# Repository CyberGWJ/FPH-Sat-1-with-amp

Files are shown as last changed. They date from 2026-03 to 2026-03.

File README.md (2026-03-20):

Designed a case for a Future Proof Homes Satillite 1 with an amplifier.  There are two version, one for a 30w amp and a large one for a 220w amp.

The design uses a slide in amp PCB base so a different amp PCB could be used without modifying the rest of the case.  

All STL and STEP files are posted.  

There is an Assembly Guide in the Docs folder.

Notes: 
Currently there are slicer files (Bambu Slicer and Orca Slicer) for multi-filament printers.  A version has been added for single filament printers (Orca Slicer only).

The LED ring has special print settings to improve the LED display.  If copying the files be sure to review the settings.

There are mounts for the LD2450 and Wi-Fi antenna.  This for the new hat version with ports on the bottom of the board.

UPDATE 3/20/2026
Added TPA3116D2 PCB, 3.5mm shielded audio cable, updated slicer files and Assembly Guide, and reorganized files.

Recommend using PCBs with an audio jack and shielded cable.

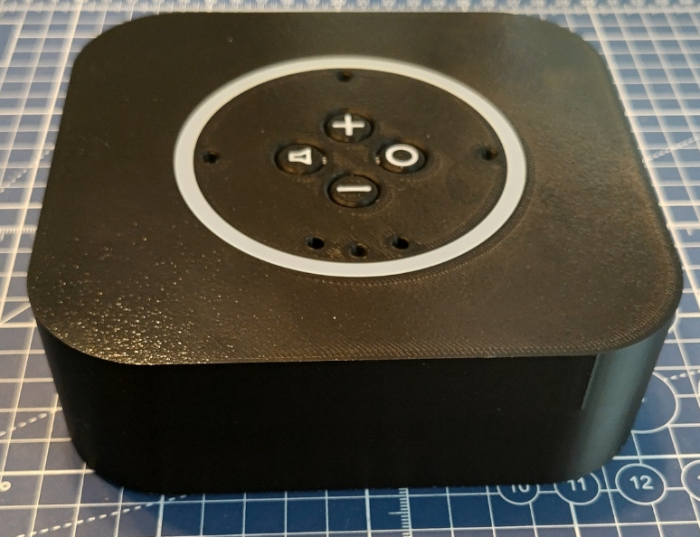
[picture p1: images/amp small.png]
Amp Case


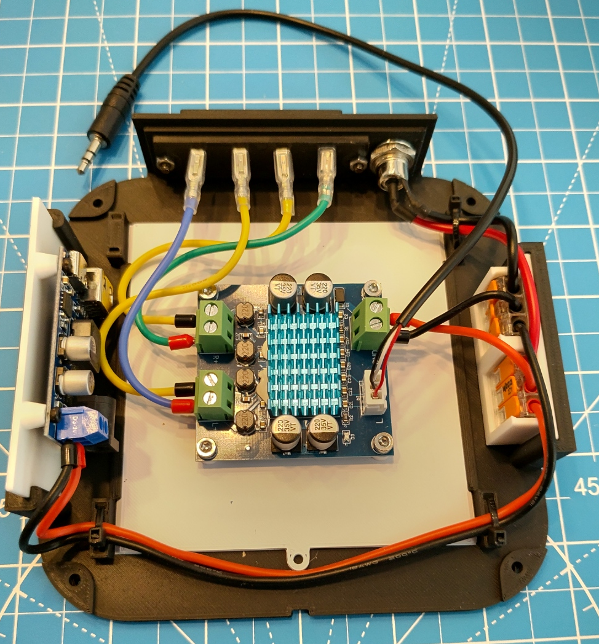
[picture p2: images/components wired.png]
Wired


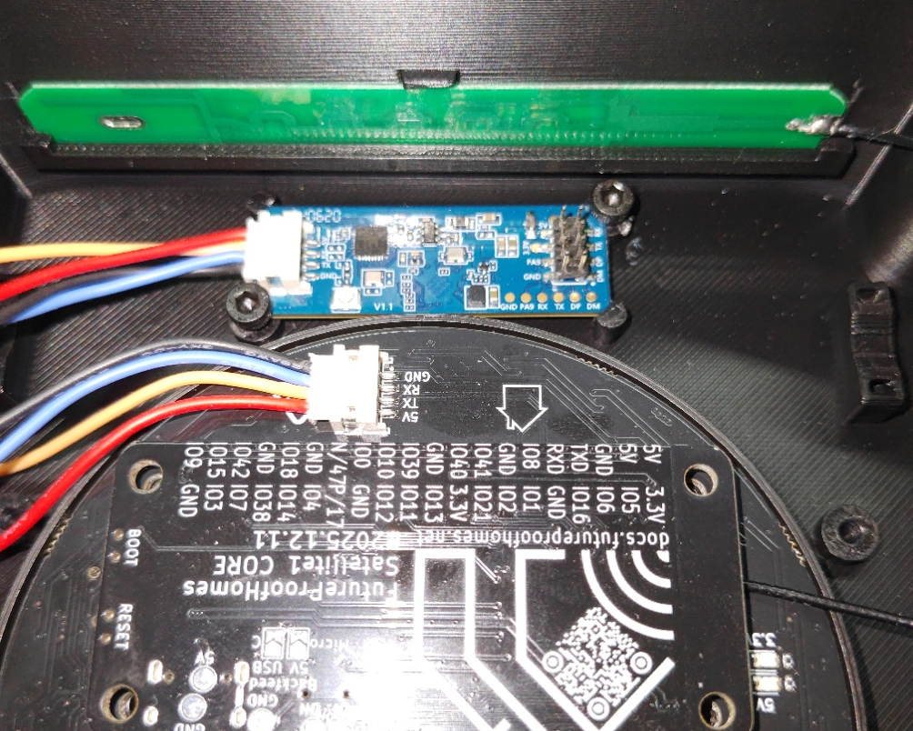
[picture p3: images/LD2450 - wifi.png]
LD2450 & Wi-Fi


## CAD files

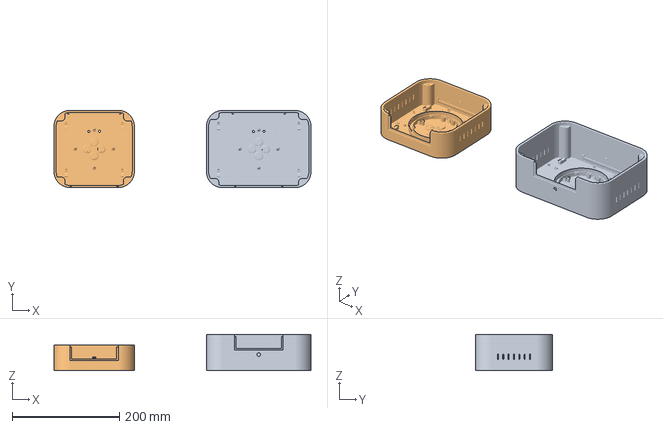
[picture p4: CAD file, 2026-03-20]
Amp Case Top - Orca Slicer MFP.3mf
479.5 x 144.2 x 67.8 mm
case top - large.step
case top.step

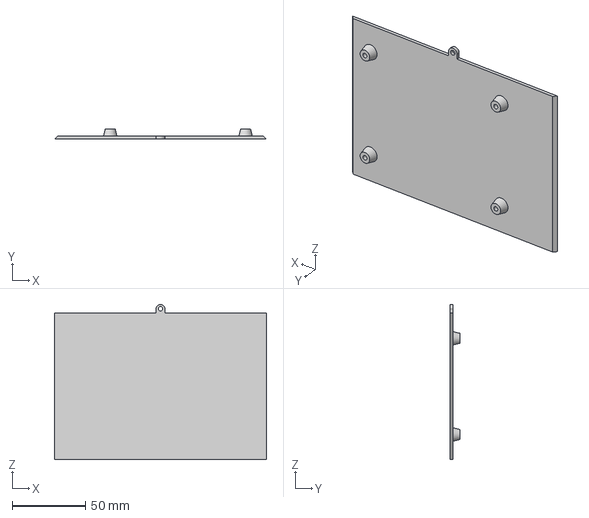
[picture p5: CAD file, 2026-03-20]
Geometry/STEP/amp pcb mount - TPA3251.step
144.8 x 7.00 x 106.0 mm

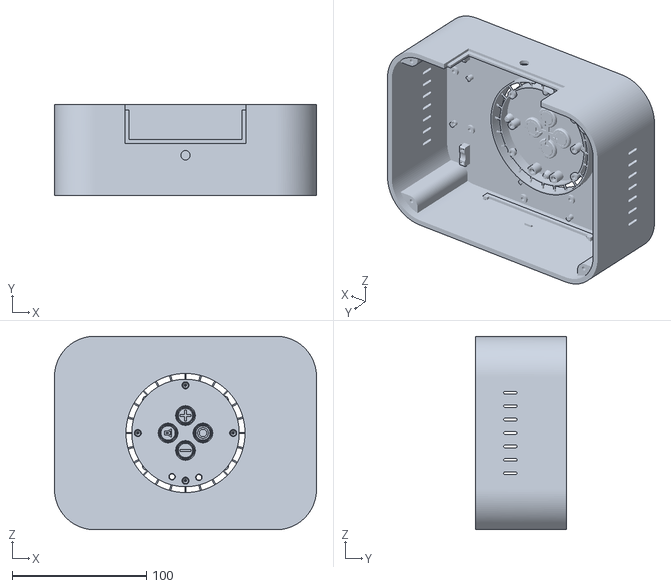
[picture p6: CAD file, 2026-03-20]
Geometry/STL/case top - large - led cutout.stl
195.0 x 67.8 x 144.0

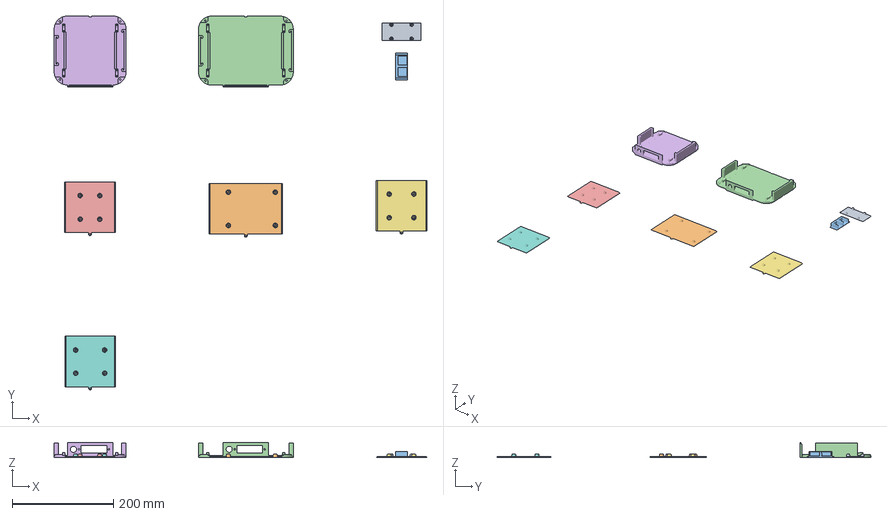
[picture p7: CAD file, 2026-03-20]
Amp Base - Orca Slicer.3mf
734.7 x 737.2 x 29.0 mm
Buck Mount.stl
amp pcb mount - TPA3251.stl
221-413.stl
amp base - large.stl
amp pcb mount - TPA3110.stl
amp base.stl
amp pcb mount - TPA3110 with mounts.stl
amp pcb mount - TPA3116D2.stl

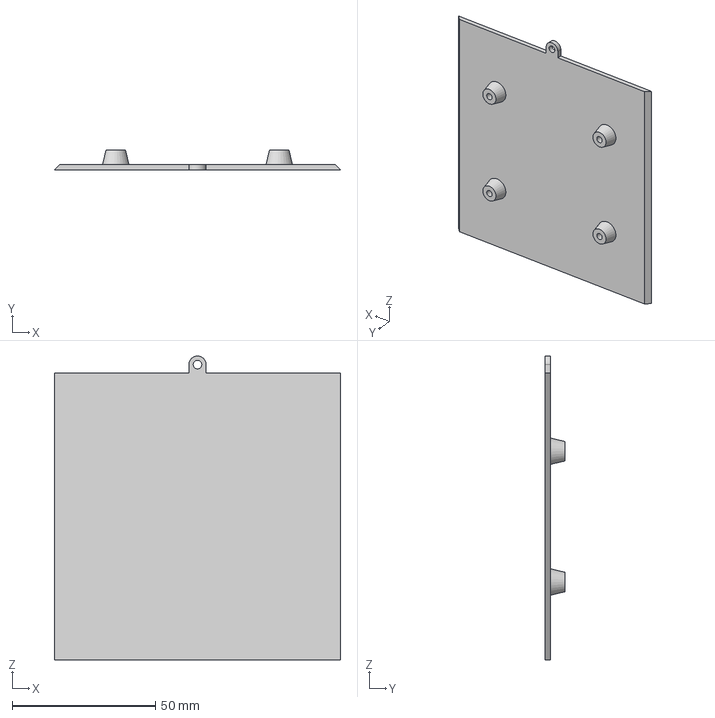
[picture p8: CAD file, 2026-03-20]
Geometry/STEP/amp pcb mount - TPA3116D2.step
99.8 x 7.00 x 106.0 mm

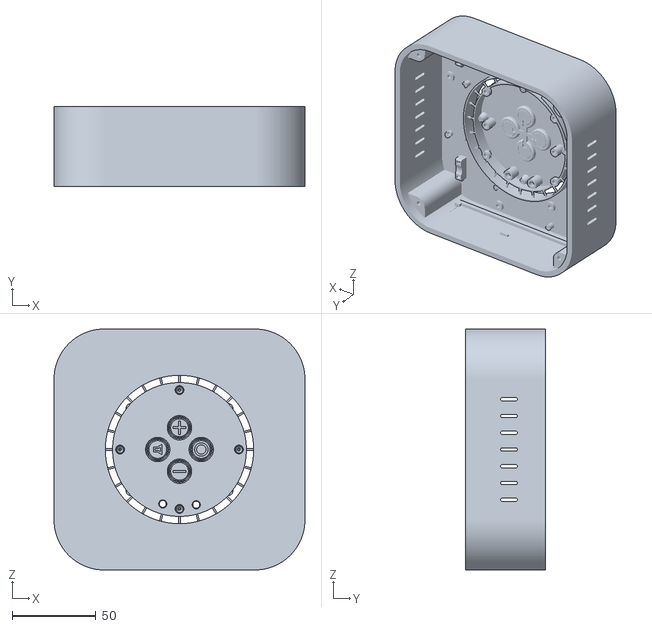
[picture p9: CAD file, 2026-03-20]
Geometry/STL/case top - led cutout.stl
150.0 x 47.8 x 144.0

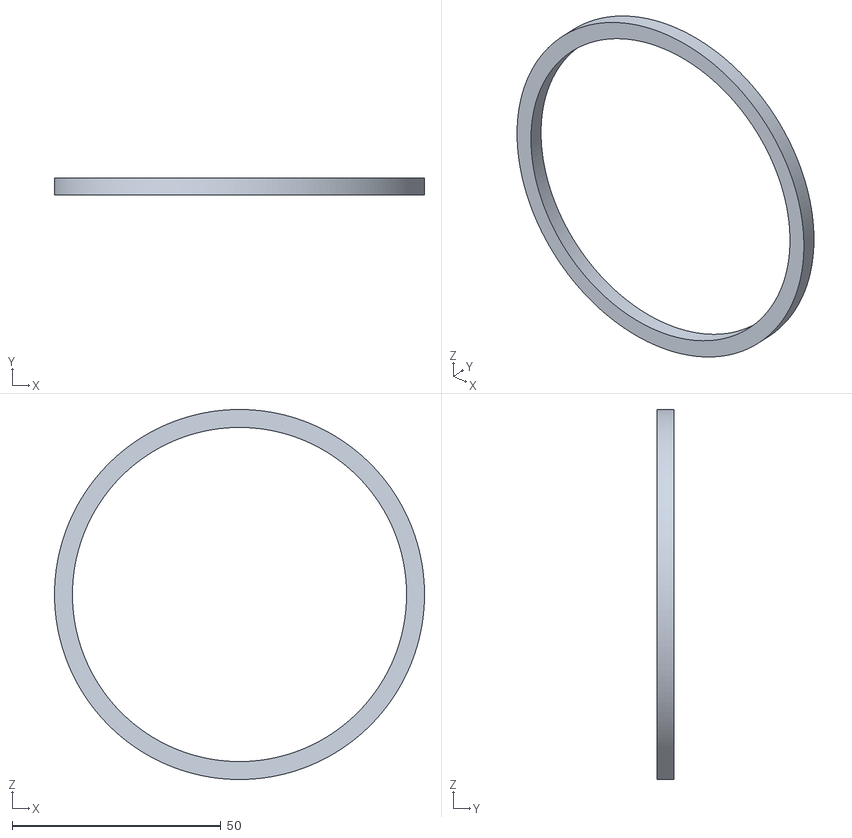
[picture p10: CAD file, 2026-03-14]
Geometry/STL/LED ring.stl
88.6 x 4.00 x 88.6

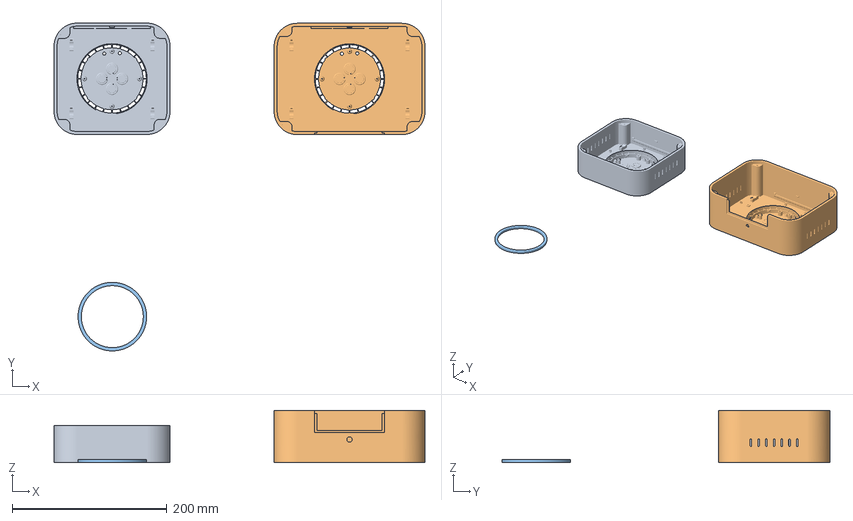
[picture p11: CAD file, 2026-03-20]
Amp Case Top - Orca Slicer SFP.3mf
479.5 x 423.7 x 67.8 mm
case top - led cutout.stl
case top - large - led cutout.stl
LED ring.stl

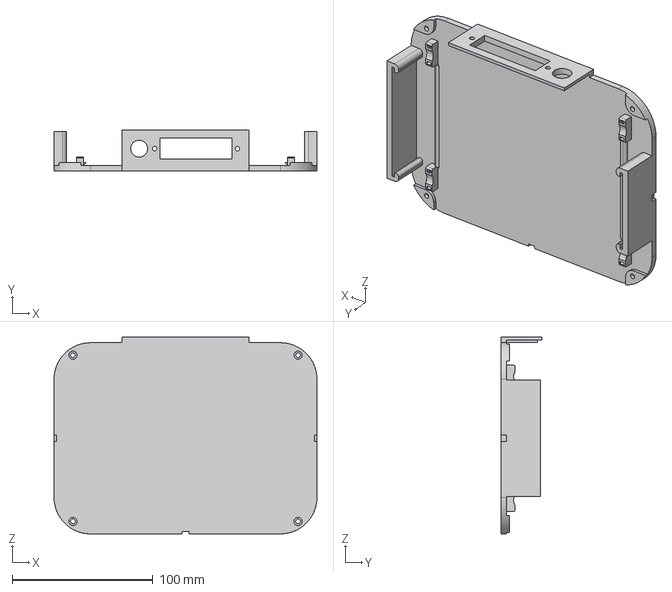
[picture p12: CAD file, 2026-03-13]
Geometry/STEP/amp base - large.step
187.0 x 29.0 x 140.0 mm

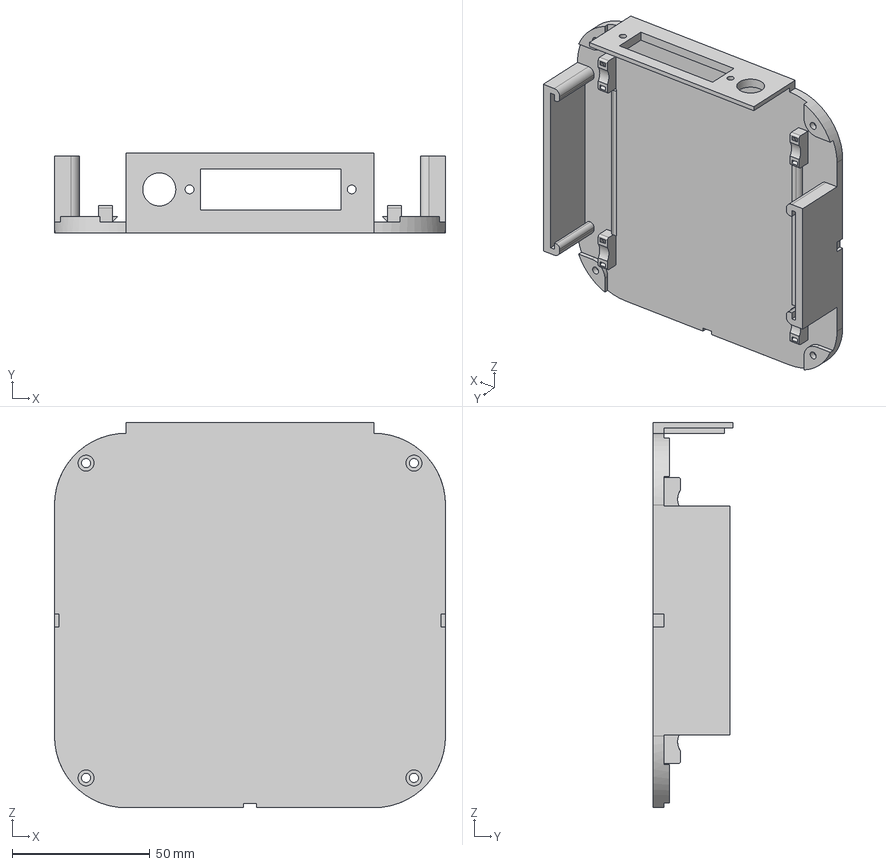
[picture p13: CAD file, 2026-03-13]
Geometry/STEP/amp base.step
142.0 x 29.0 x 140.0 mm

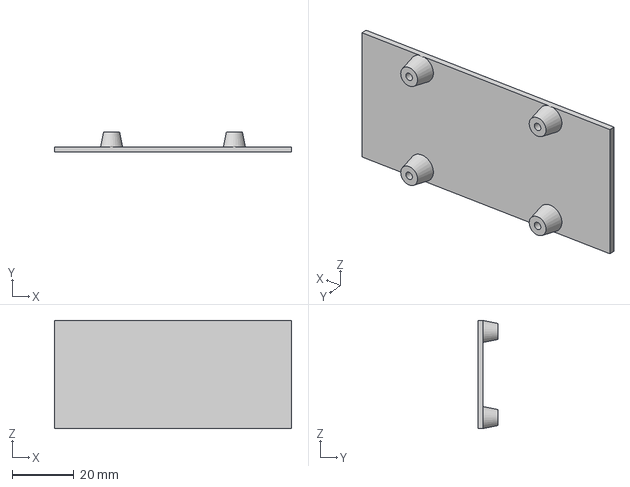
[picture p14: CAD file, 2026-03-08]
Geometry/STEP/buck mount.step
76.8 x 6.60 x 35.0 mm

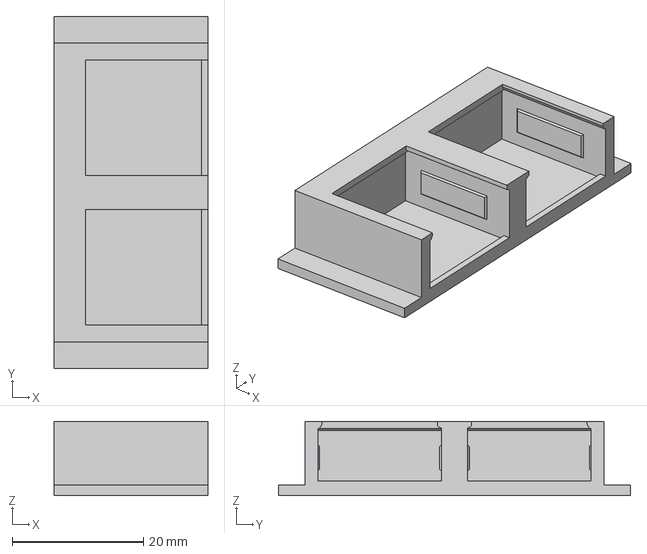
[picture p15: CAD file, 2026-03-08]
Geometry/STEP/wago 221-413.step
23.4 x 53.6 x 11.3 mm

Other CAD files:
Amp Base - Bambu Studio.3mf
Geometry/STEP/case top - large.step
Amp Case Top - Bambu Studio MFP.3mf
Geometry/STEP/amp pcb mount - TPA3110 with mounts.step
Geometry/STEP/amp pcb mount - TPA3110.step
Geometry/STEP/case top.step
Geometry/STEP/amp pcb mount - large.step
Geometry/STL/Buck Mount.stl
Geometry/STL/amp base - large.stl
Geometry/STL/amp base.stl
Geometry/STL/amp pcb mount - TPA3110 with mounts.stl
Geometry/STL/amp pcb mount - TPA3110.stl
Geometry/STL/amp pcb mount - TPA3116D2.stl
Geometry/STL/amp pcb mount - TPA3251.stl
Geometry/STL/wago 221-413.stl

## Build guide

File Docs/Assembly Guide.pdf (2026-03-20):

# FPH Sat-1 Amp assembly

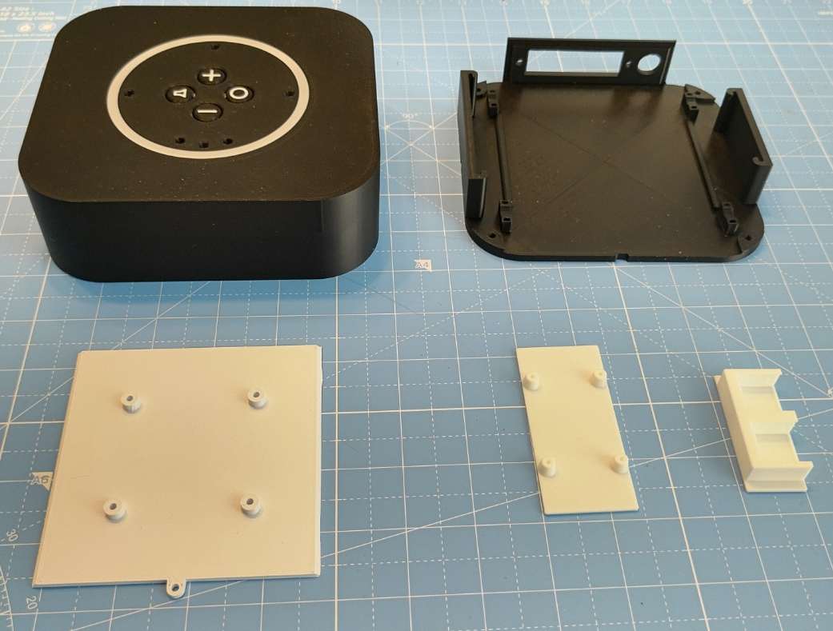
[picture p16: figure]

Printed Parts: (Small case shown)

### 1. Top (Large) 2. Amp Base (Large) 3. Amp PCB Mount (Large) 4. Wago Connector Insert 5. Buck Converter Insert

Filament
Standard settings
No supports are required
The LED ring has special print settings Use Transparent or Basic White Power
Testing was done using a DC 12V 3 Amp
& 24V 4 Amp power adapters.
Check specifications of PCB if using other PSU USE AT YOUR OWN RISK!

# FPH Sat-1 Amp assembly

BOM (links to sources at end of guide)

### 1. M3x4 screws - 6 2. M3x4 to M3x8 screws – 2

a. Sat1

### 3. M3x8 to M3x10 screws – 8

a. Sat1 & Speaker Term Block

### 4. M3 nuts – 2 (Speaker Term Block) 5. M2x4 screws – 4 (Buck converter)

6. 16 or 18 AWG wire (red / black)

### 7. Ferrules crimp connectors

a. (optional)

### 8. Wago 221-413 – 2 9. Buck Converter 10. Amp Small

a. TPA3110 (2 versions) & TPA3116D2

### 11. Amp Large

a. Zk-2202-W Class D Amp (TPA3251)

### 12. DC power jack 13. Speaker Terminal Block

14. 2.8 female spade connector

### 15. Right Angle USB-C Cable (options)

16. 3.5mm Audio Cable (options)

# FPH Sat-1 Amp assembly

Assembly
Assembly is the same for both sizes

DC Power Jack

### 1. Insert into base 2. Add washer and nut 3. Tighten with fingers 4. Use wrench to finish tightening

Speaker Terminal Block

### 1. Insert Block with spring clip down

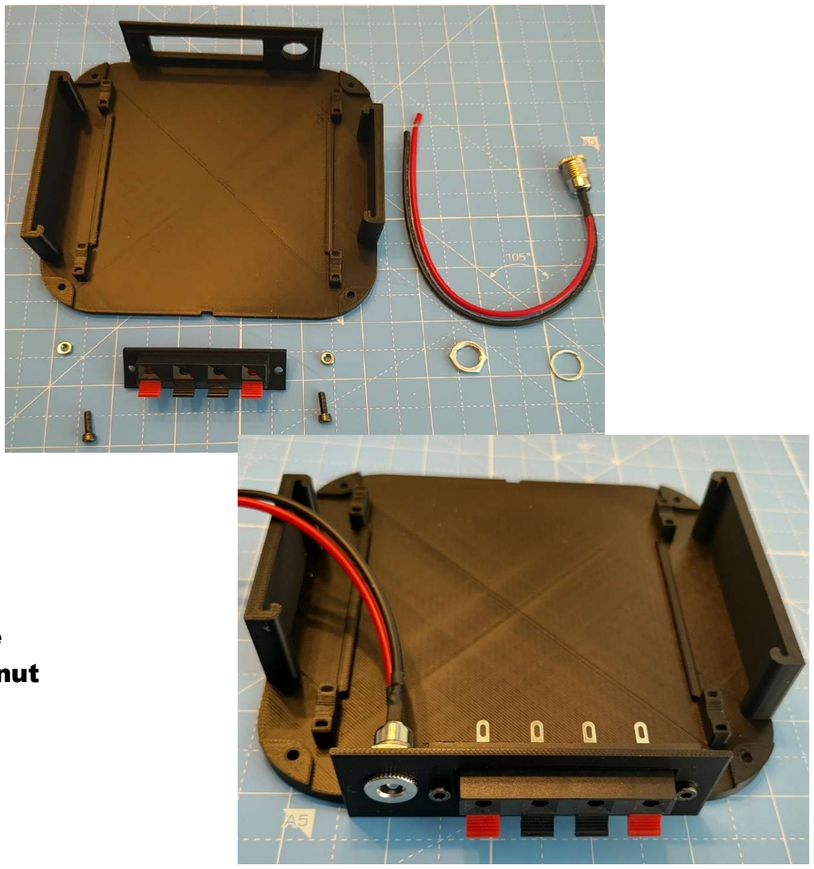
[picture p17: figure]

a. Insert from inside the Amp Base

### 2. Insert M3 screws from rear and add nut 3. Lightly Tighten 4. Add second M3 screw and add nut 5. Tighten both securely

# FPH Sat-1 Amp assembly

Wago Connectors

### 1. Insert the two 221-413 into slots 2. Slide the mount into the side

Buck Converter

### 1. Mount converter using the 4 M2x4

screws

### 2. Slide the converter into the with

USB-C port facing the rear

Amp

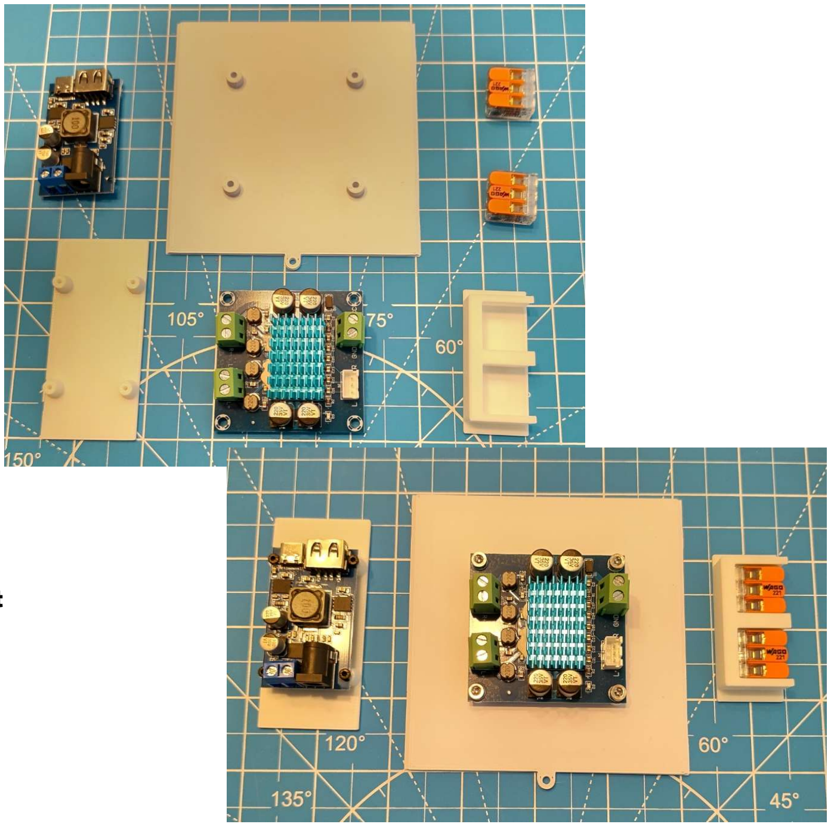
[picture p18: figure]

### 1. Mount the Amp on the AMP PCB mount 2. Use 4 M3x4 screws 3. Slide the PCB mount on to base

# FPH Sat-1 Amp assembly

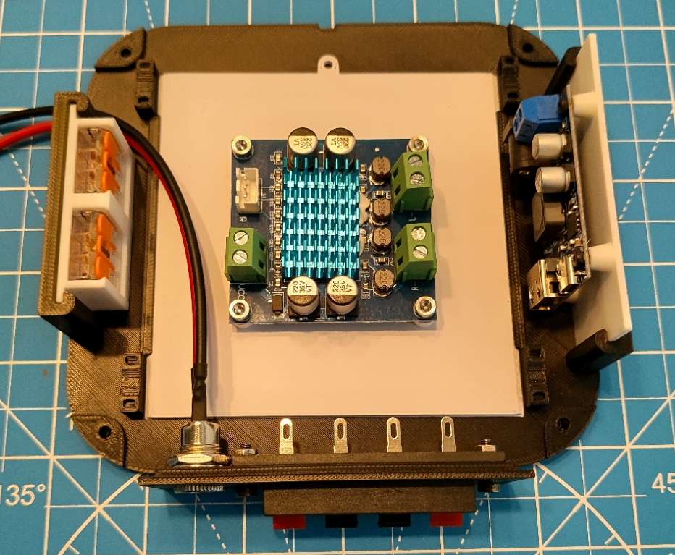
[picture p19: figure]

Wire Lengths (longest)

Small Case
1.Buck Converter to Wago – 200mm 2.Amp to Wago – 50mm
3.Amp to Speaker Block – 100mm

Large Case
1.Buck Converter to Wago – 250mm 2.Amp to Wago – 50mm
3.Amp to Speaker Block – 170mm

# FPH Sat-1 Amp assembly

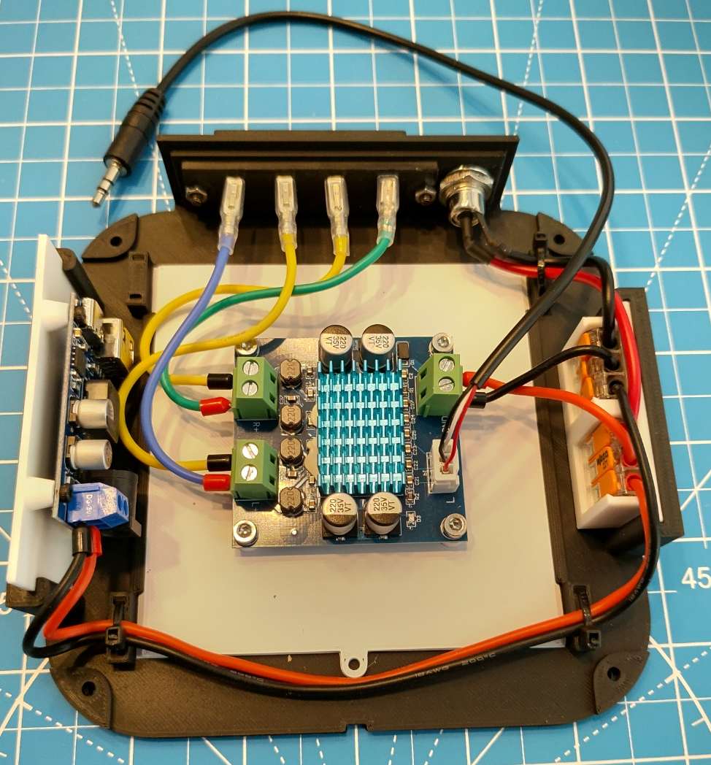
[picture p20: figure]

Cut Power wires to fit
Cut wires to length as needed

Crimp 2.8 female spade connectors

If using ferrules connectors, crimp now Note: Makes inserting wire into connectors easier.

### Caution:

Be sure to double check when connecting wires.

There are zip ties blocks at the corners to tie down wires if needed.

# FPH Sat-1 Amp assembly

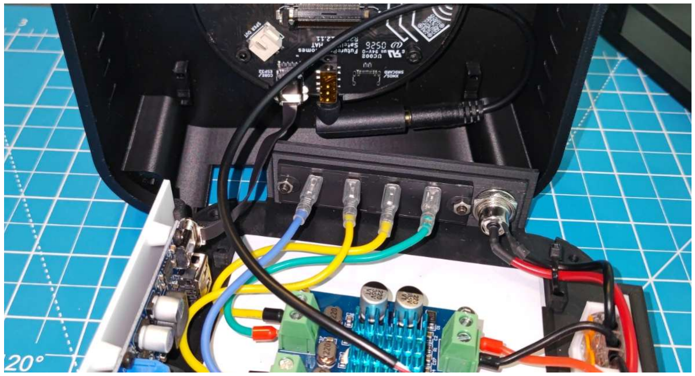
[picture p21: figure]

Once all the wires are connected. Recheck each connection.

Attach the USC-C cable to Sat1. Attach 3.5mm audio cable.
Attach speakers to speaker block.

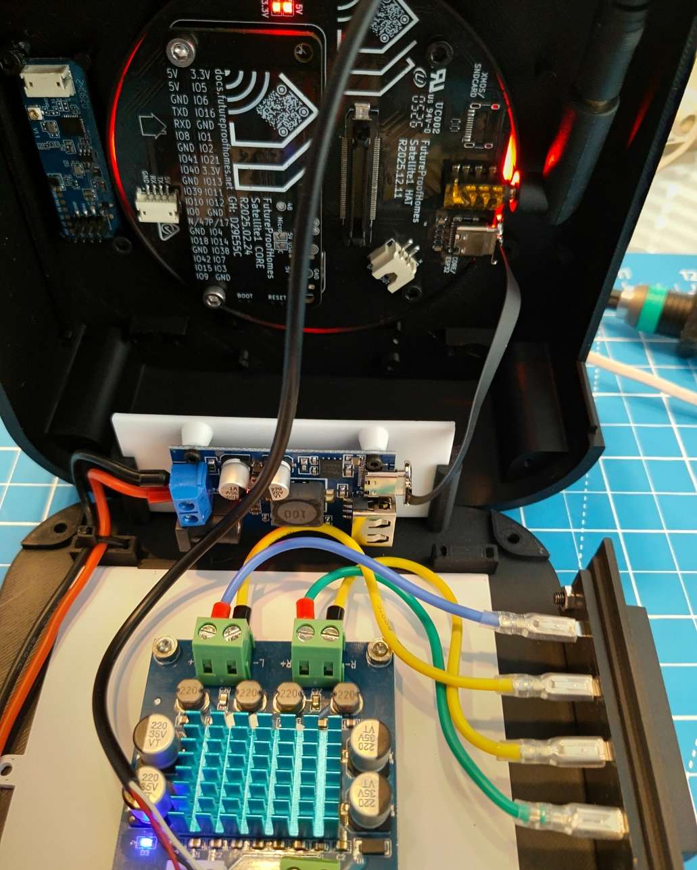
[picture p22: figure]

# FPH Sat-1 Amp assembly

Amp Large – turn knob to off position If all looks good, plug in power.
Amp Large – turn on amp, slowly turn up

There should be lights on PCBs and Sat1 There may be an initial pop on the speakers If there are no lights on PCBs, check Wago’s If there is no audio, check wiring at block

Finally
Slide to the two parts together
Use 4 M3x8 screws to secure bottom to top,

# FPH Sat-1 Amp assembly

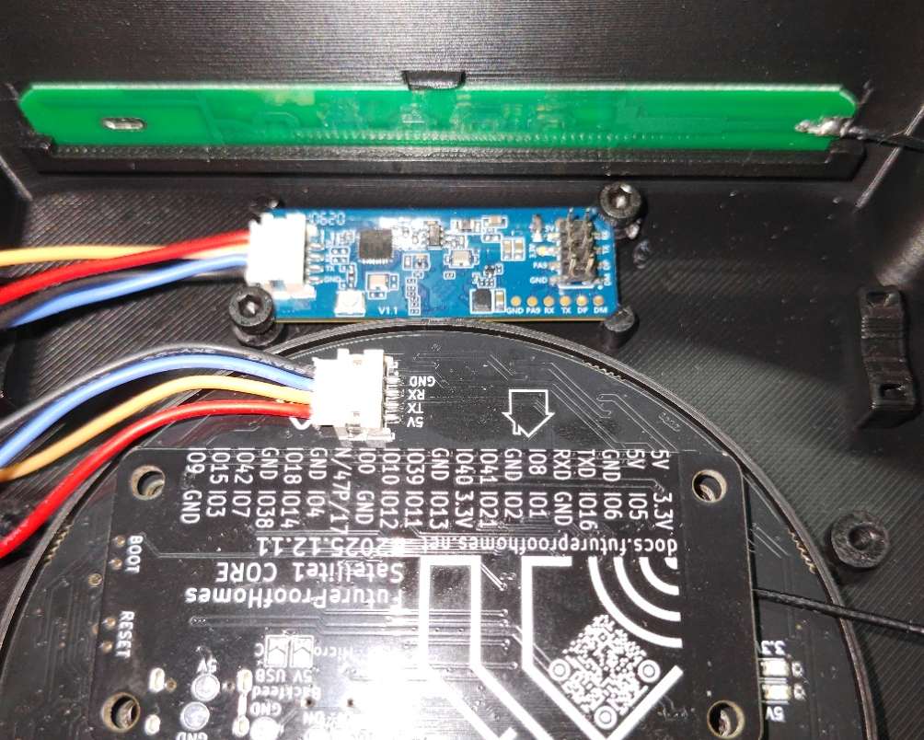
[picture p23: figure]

New LD2450 and Wi-Fi antenna mounts

There are 4 mounting places for the LD2450 The board is held in be 2 M3x4 screws

### 1. Get the screws started in the corners 2. Slide the board in 3. Set it in cutouts in opposite corners 4. Tighten screws until contact

Note: if wiring a cable the RX goes to TX and TX goes to RX

he Wi-Fi antenna slides in the slot and the clip at the top holds it in place.

To remove the antenna gently pull on the middle and pull up on the end

# FPH Sat-1 Amp assembly

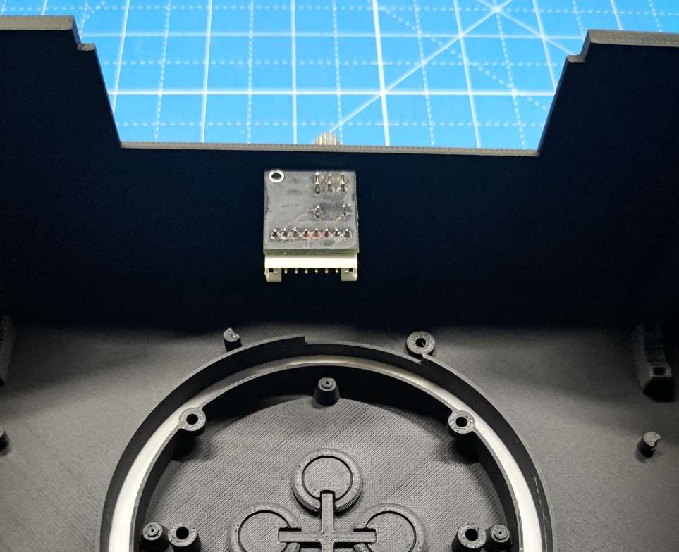
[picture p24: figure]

TPA3251 Volume Knob Mount

The mount has moved to the rear for a cleaner look.

There is a knotch at the top for the tab on the knob.

### 1. Mount the knob with the PCB on the top 2. Press the knob into the hole

a. It should snap in place

### 3. Tighten with wrench

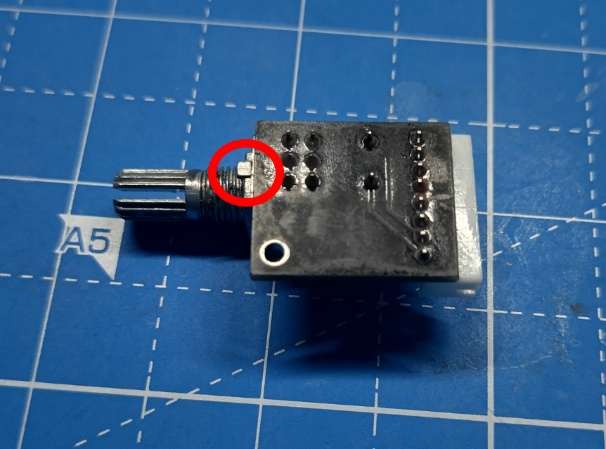
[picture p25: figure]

# FPH Sat-1 Amp assembly

Source Links (what I used)

M3 Screws and Nuts and M2 Screws
Any source will work

Wire – 18 AWG (multi color, silicone) https://www.amazon.com/dp/B09Y856K8J?ref_=ppx_hzsearch_conn_dt_b_fed_asin_title_21&th=1

Ferrules Connectors (Optional) https://www.amazon.com/dp/B0FKYK38RZ?ref=ppx_yo2ov_dt_b_fed_asin_title&th=1 Crimper
https://www.amazon.com/dp/B0D7ZVC29K?ref=ppx_yo2ov_dt_b_fed_asin_title&th=1

# FPH Sat-1 Amp assembly

Wago (Recommend buying a multi pack)
Multi-pack
https://www.amazon.com/dp/B0BN6MBR7X?ref_=ppx_hzsearch_conn_dt_b_fed_asin_title_5

221-413 (alone)
https://www.amazon.com/WAGO-221-413-Lever-Nuts-3-Conductor-Connectors/dp/B07W94XJSN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 0diYVfWMiQJVcCrLRBeJPmnQuniNHTXBQg8uYtRSu9JXM2ifpG0bCjhoBeuX7ptKaH3W aMrSANeaO8dis6w9rc-e2NZMHdxRsW-CsT-6toGhLNJHUpFwSpulw4KGRKmuu54BbPJitgI0n5IVeJd9LJNi9FKSNk2V9D7yvYF5tRu ECZmMoM7tD2URH5Dy4Hc-CzaiEcEK7cttnuptYC2YM9O3DOR2jNL6Kvow7s8mTYaRdC46nEnbE1_OZSU8yle3wI6Y hkFuRFnfPCyyoPP7WagPLFG0aDMnOWwuSVJhc.bfXd7ykWwURaMslUhVobx901-VUtyxUBJU5hjRk-ZdE&dib_tag=se&keywords=wago%2B221-413&qid=1772046604&s=hi&sprefix=wago%2B221-41%2Ctools%2C256&sr=1-1&th=1

# FPH Sat-1 Amp assembly

Buck Converter
https://www.amazon.com/dp/B0D146WV15?ref=ppx_yo2ov_dt_b_fed_asin_title&th=1

Amp – Small without connectors (TPA3110) https://www.amazon.com/dp/B0CY9C1936?ref=ppx_yo2ov_dt_b_fed_asin_title

Amp – Small with connectors (TPA3110) https://www.aliexpress.us/item/3256807803112323.html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

AMP – Small with 3.5mm audio jack (TPA3116D2) - RECOMMENDED https://www.amazon.com/dp/B08NFCCGC2?ref=ppx_yo2ov_dt_b_fed_asin_title

Amp – Large – (TPA3251) - RECOMMENDED https://www.amazon.com/dp/B0DSPLN2QC?ref=ppx_yo2ov_dt_b_fed_asin_title

# FPH Sat-1 Amp assembly

DC Power Jack
https://www.amazon.com/dp/B0DLKN8J7M?ref=ppx_yo2ov_dt_b_fed_asin_title

Speaker Terminal Block
https://www.amazon.com/dp/B08YMZ88Z5?ref=ppx_yo2ov_dt_b_fed_asin_title

Spade Connector
https://www.amazon.com/dp/B07FCFH84Q?ref_=ppx_hzsearch_conn_dt_b_fed_asin_title_28&th=1

USB-C Cables (These were used and worked) https://www.amazon.com/dp/B0G439K5W9?ref=ppx_yo2ov_dt_b_fed_asin_title&th=1

https://www.amazon.com/dp/B0FJF1M4CT?ref=ppx_yo2ov_dt_b_fed_asin_title&th=1

https://www.amazon.com/dp/B0F8HX6HQZ?ref=ppx_yo2ov_dt_b_fed_asin_title&th=1

# FPH Sat-1 Amp assembly

3.5MM Audio Cable

JST Connector
https://www.amazon.com/dp/B0DPF3FMJK?ref=ppx_yo2ov_dt_b_fed_asin_title

### 90 Degree Audio Jacks

https://www.amazon.com/dp/B09CDC1MV9?ref_=ppx_hzsearch_conn_dt_b_fed_asin_title_13

3.5mm male both ends
https://www.amazon.com/dp/B074QHNY5Q?ref=ppx_yo2ov_dt_b_fed_asin_title

3.5mm male both ends shielded – RECOMMENTED https://www.amazon.com/dp/B082PLZB54?ref=ppx_yo2ov_dt_b_fed_asin_title

# FPH Sat-1 Amp assembly

LD2450
https://www.amazon.com/dp/B0CQ2P4RVP?ref_=ppx_hzsearch_conn_dt_b_fed_asin_title_3&th=1

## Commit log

2026-03-08 Create initial dirs and files
    [Amp Case - Bambu Studio MFP.3mf, Buck Mount.stl, amp base - large.step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]
2026-03-08 Added Orca Slicer file
    [Amp Case - Orca Slicer MFP.3mf]
2026-03-10 Updated files for LD2450 and wifi mounts
    [Amp Case - Bambu Studio MFP.3mf, case top - large.step, case top.step]
2026-03-13 Updated files for LD2450 and WiFi and PDF
    [Amp Case - Bambu Studio MFP.3mf, Amp Case - Orca Slicer MFP.3mf, amp base - large.step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]
2026-03-14 Updated Assembly Guide
2026-03-14 Added single filament printer files
    [Amp Case - Orca Slicer SFP.3mf, LED ring.stl, case top - large - led cutout.stl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]
2026-03-20 Reorg files, updated guide, and added TPA3116D2
    [Amp Base - Bambu Studio.3mf, Amp Base - Orca Slicer.3mf, Amp Case Top - Bambu Studio MFP.3mf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]
